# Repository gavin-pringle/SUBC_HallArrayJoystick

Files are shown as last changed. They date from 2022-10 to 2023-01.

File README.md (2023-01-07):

# SUBC - Hall-Effect Sensor Array Joystick

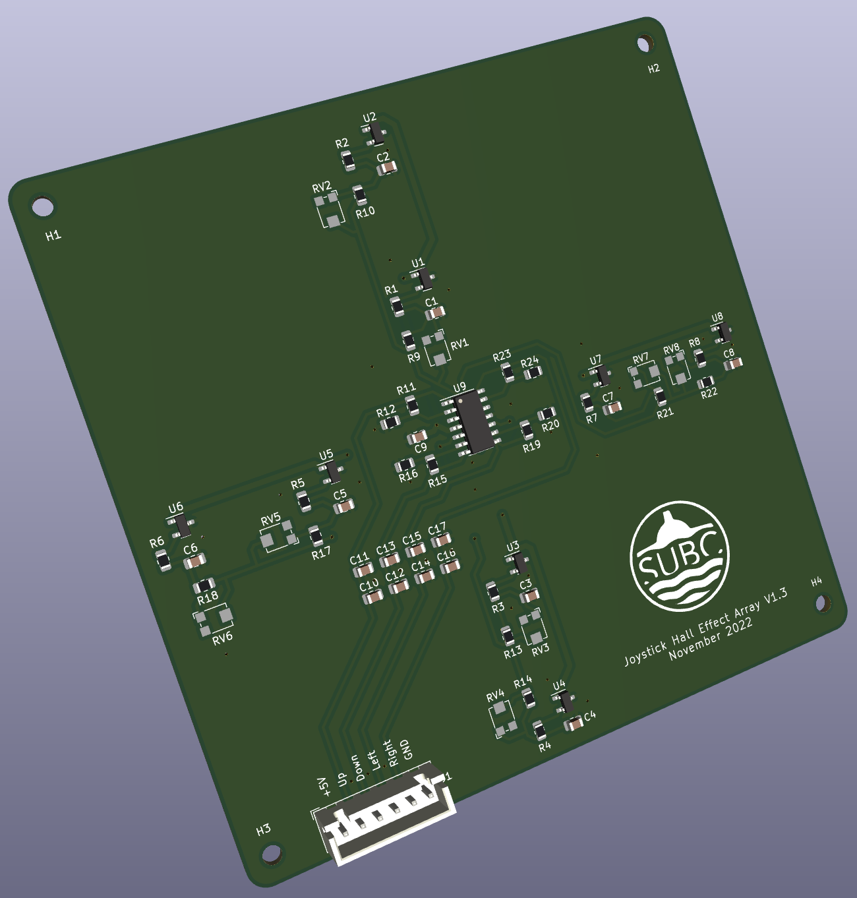
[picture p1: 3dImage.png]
PCB 3D Render


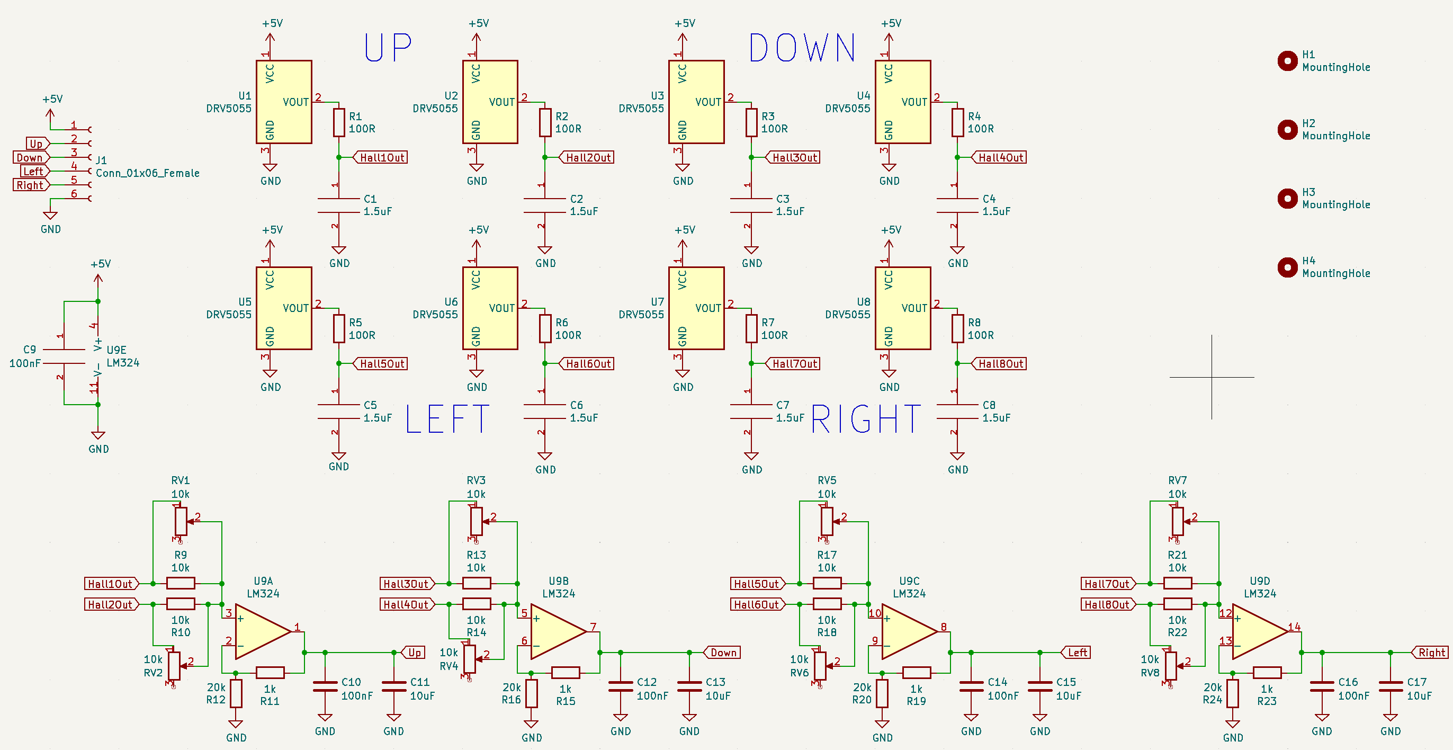
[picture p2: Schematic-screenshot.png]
Schematic Screenshot


## Use Case

- For use in pilot's joystick controlling pitch and yaw for [SUBC](subc.ca)'s 2023 human powered submarine.
- A 3D printed assembly is being designed to house and guide a magnet to travel along the up-down and left-right axes of the PCBA. This magnet is connected to a joystick handle that is contrained to move along these same axes. When the pilot positions the magnet in a certain direction the magnet activates the hall-effect sensors in that direction. The quad op-amp IC in the center of the PCB produces a weighted average of the hall-effect outputs for each direction, weighting greater the sensor further from the center. Each output from the op-amp IC is connected to its labelled output pin in the JST connector.
- This design allows for easier waterproofing by excluding the use of potentiometers.

## Technical Specifications

- Two layer PCB, 100x100mm.
- Uses eight [DRV5055 SMD linear hall-effect sensors](https://www.ti.com/lit/ds/symlink/drv5055.pdf).
- Uses an [SMD quad op-amp](https://www.ti.com/lit/ds/symlink/lm2902-n.pdf) to average both hall-effect outputs in each direction (up, down, left, right).
- Single six pin JST connector containing PWR, GND, and analog outputs for each direction.
- Since connector is only through-hole component, entire PCBA can be easily waterproofed with potting compound for use in submarine.
- Current revision has extra traces and pads for optionally adding trimmer pots to tune hall effect sensor weighting.

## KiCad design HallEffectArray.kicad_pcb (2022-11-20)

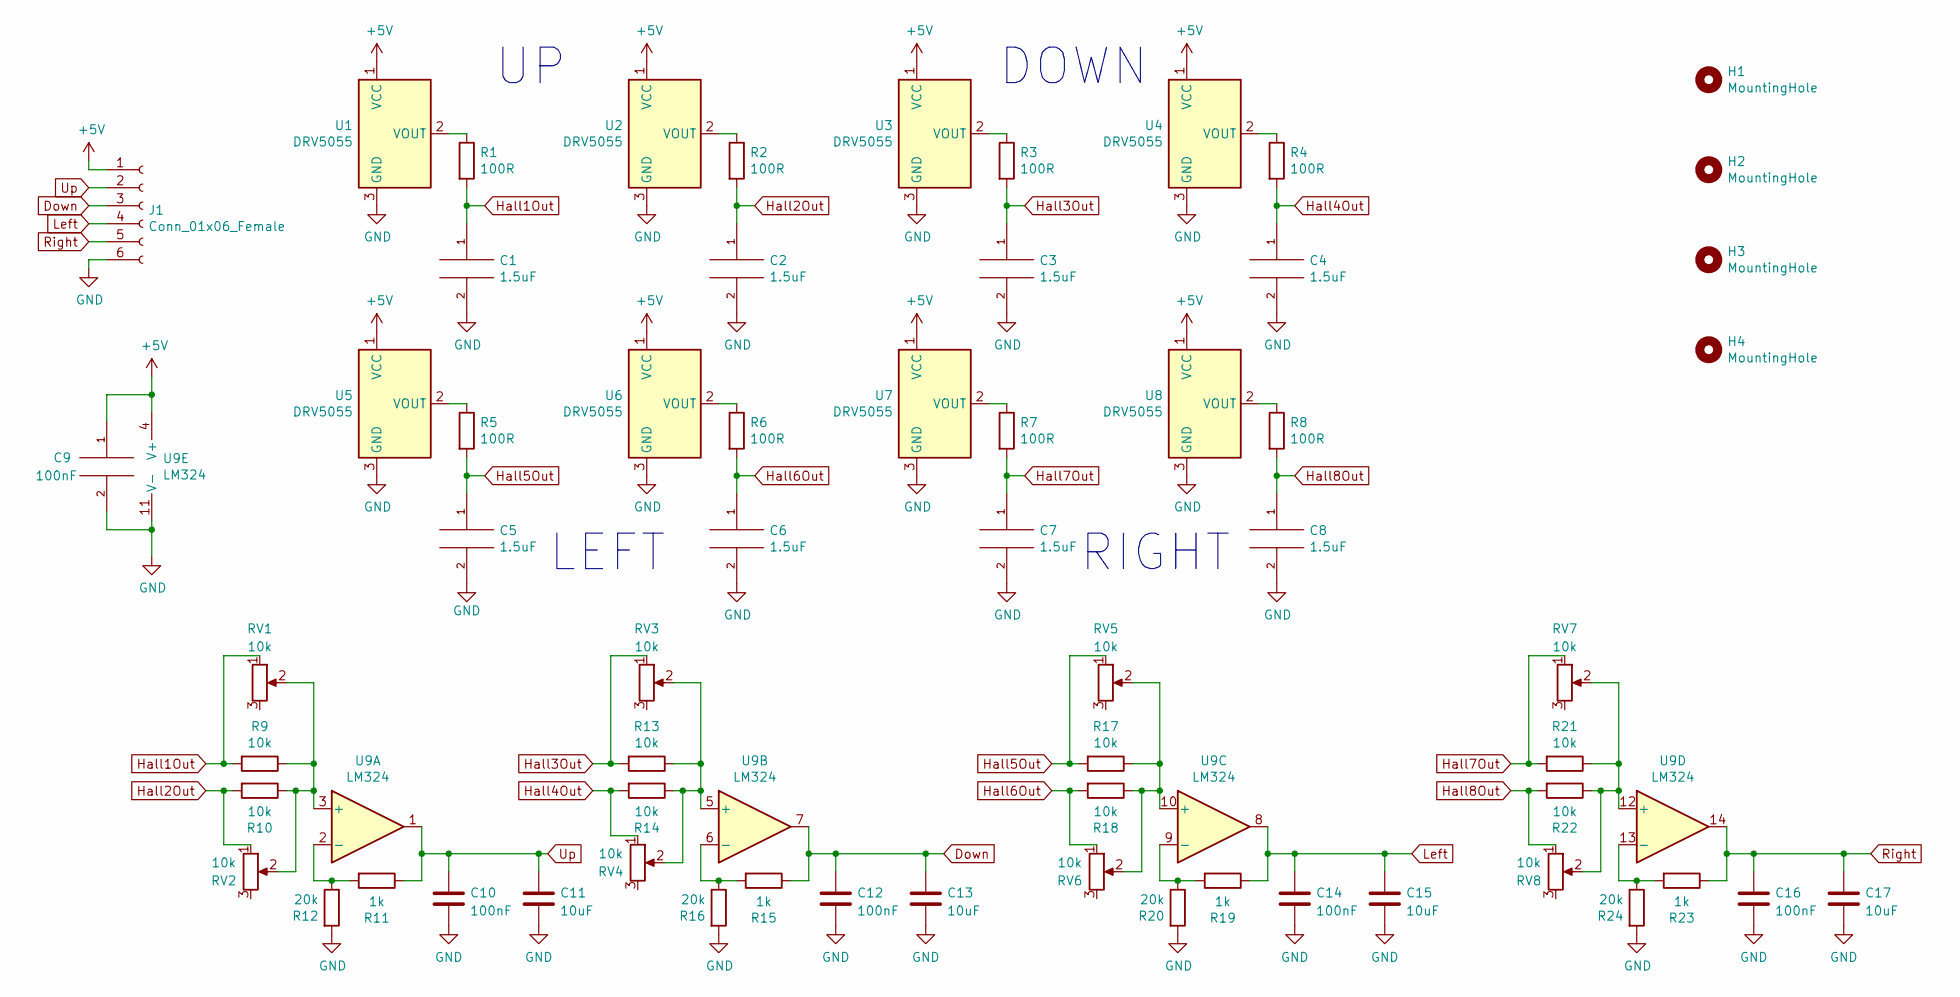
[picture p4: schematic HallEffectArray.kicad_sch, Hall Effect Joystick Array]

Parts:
C1, C2, C3, C4, C5, C6, C7, C8: 1.5uF; C_0805_2012Metric
C9, C10, C12, C14, C16: 100nF; C_0805_2012Metric
C11, C13, C15, C17: 10uF; C_0805_2012Metric
H1, H2, H3, H4: MountingHole; MountingHole_2.7mm_M2.5
J1: Conn_01x06_Female; JST_XH_B6B-XH-A_1x06_P2.50mm_Vertical
R1, R2, R3, R4, R5, R6, R7, R8: 100R; R_0805_2012Metric
R9, R10, R13, R14, R17, R18, R21, R22: 10k; R_0805_2012Metric
R11, R15, R19, R23: 1k; R_0805_2012Metric
R12, R16, R20, R24: 20k; R_0805_2012Metric
RV1, RV2, RV3, RV4, RV5, RV6, RV7, RV8: 10k; Potentiometer_Bourns_TC33X_Vertical
U1, U2, U3, U4, U5, U6, U7, U8: DRV5055; SOT-23
U9: LM324; SOIC-14_3.9x8.7mm_P1.27mm

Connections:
+5V: C9.1, J1.1, U1.1 (VCC), U2.1 (VCC), U3.1 (VCC), U4.1 (VCC), U5.1 (VCC), U6.1 (VCC), U7.1 (VCC), U8.1 (VCC), U9.4 (V+)
Down: C12.1, C13.1, J1.3, R15.1, U9.7
GND: C1.2, C2.2, C3.2, C4.2, C5.2, C6.2, C7.2, C8.2, C9.2, C10.2, C11.2, C12.2, C13.2, C14.2, C15.2, C16.2, C17.2, J1.6, R12.2, R16.2, R20.2, R24.2, U1.3 (GND), U2.3 (GND), U3.3 (GND), U4.3 (GND), U5.3 (GND), U6.3 (GND), U7.3 (GND), U8.3 (GND), U9.11 (V-)
Hall1Out: C1.1, R1.2, R9.2, RV1.1
Hall2Out: C2.1, R2.2, R10.2, RV2.1
Hall3Out: C3.1, R3.2, R13.2, RV3.1
Hall4Out: C4.1, R4.2, R14.2, RV4.1
Hall5Out: C5.1, R5.2, R17.2, RV5.1
Hall6Out: C6.1, R6.2, R18.2, RV6.1
Hall7Out: C7.1, R7.2, R21.2, RV7.1
Hall8Out: C8.1, R8.2, R22.2, RV8.1
Left: C14.1, C15.1, J1.4, R19.1, U9.8
unnamed: R1.1, U1.2 (VOUT)
unnamed: R2.1, U2.2 (VOUT)
unnamed: R3.1, U3.2 (VOUT)
unnamed: R4.1, U4.2 (VOUT)
unnamed: R5.1, U5.2 (VOUT)
unnamed: R6.1, U6.2 (VOUT)
unnamed: R7.1, U7.2 (VOUT)
unnamed: R8.1, U8.2 (VOUT)
unnamed: R9.1, R10.1, RV1.2, RV2.2, U9.3 (+)
unnamed: R11.2, R12.1, U9.2 (-)
unnamed: R13.1, R14.1, RV3.2, RV4.2, U9.5 (+)
unnamed: R15.2, R16.1, U9.6 (-)
unnamed: R17.1, R18.1, RV5.2, RV6.2, U9.10 (+)
unnamed: R19.2, R20.1, U9.9 (-)
unnamed: R21.1, R22.1, RV7.2, RV8.2, U9.12 (+)
unnamed: R23.2, R24.1, U9.13 (-)
Right: C16.1, C17.1, J1.5, R23.1, U9.14
Up: C10.1, C11.1, J1.2, R11.1, U9.1

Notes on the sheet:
DOWN
RIGHT
LEFT

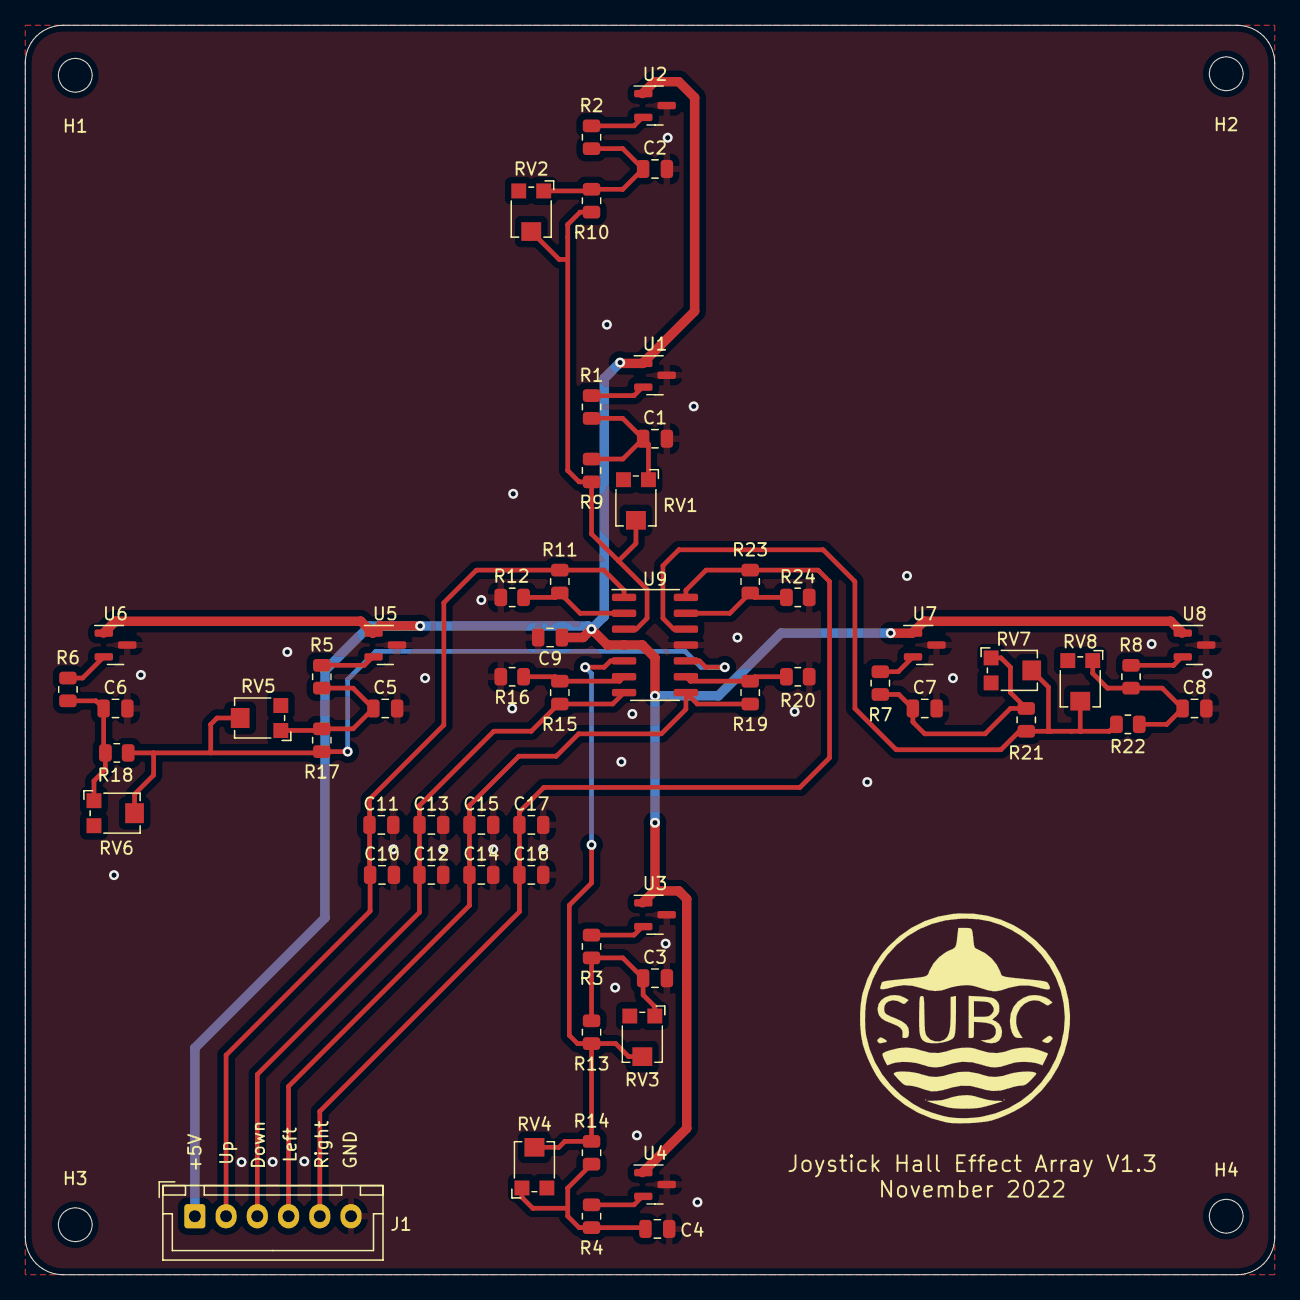
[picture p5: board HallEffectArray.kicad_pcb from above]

Board: 2 copper layers, 100.0 x 100.0 mm, 63 parts (0 on the bottom side), 30 nets.

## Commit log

2022-10-22 v1.1, traces adjusted
    [HallEffectArray.kicad_pcb, HallEffectArray.kicad_sch, HallEffectArray.sch]
2022-11-06 Deleted unchanged files from older version of Kicad
    [HallEffectArray.sch]
2022-11-06 Version 1.2: Added trimmer pots, bypass capacitors, vias, board size now 100x100mm
    [HallEffectArray.kicad_pcb, HallEffectArray.kicad_sch]
2022-11-20 V1.3: Added decoupling caps on outputs, more vias, changed datasheet
    [HallEffectArray.kicad_pcb, HallEffectArray.kicad_sch]
2023-01-07 Added 3D render of PCB
2023-01-07 Added schematic screenshot
